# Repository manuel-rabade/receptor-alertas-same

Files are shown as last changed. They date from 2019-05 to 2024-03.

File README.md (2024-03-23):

# Receptor alertas SAME

Este deposito contiene el diseño de hardware y código fuente de mi trabajo de tesis, titulado [Sistema embebido para recibir alertas de riesgo codificadas con el protocolo SAME](http://www.ptolomeo.unam.mx:8080/xmlui/handle/RepoFi/18971), el cual realice para obtener el título de Ingeniero en Computación en la Facultad de Ingeniería de la Universidad Nacional Autónoma de México.

Como resultado de mi proyecto de titulación, se desarrolló un sistema embebido capaz de recibir alertas de riesgo transmitidas mediante el protocolo SAME y difundirlas a través de medios visuales, auditivos o electrónicos. Además, se documentan las bases técnicas para el desarrollo de productos o servicios que amplíen el aprovechamiento y la cobertura de los sistemas de alerta de riesgos.

## Organización

- [hardware](hardware): Diagrama esquemático, diseño de la placa electrónica y lista de componentes electrónicos del receptor.
- [software](software): Implementación del software del receptor. Código fuente de las pruebas unitarias y de integración.
- [logger](logger): Scripts y configuración para recolectar registros de operación.
- [prototipo](prototipo): Diagrama esquemático y software del prototipo del receptor.

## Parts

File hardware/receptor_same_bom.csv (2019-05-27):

Qty | Value | Device | Package | Parts | Description | HOUSEPART | MF | MPN | OC_FARNELL | OC_NEWARK | POPULATE | PROD_ID | SPICEPREFIX | URL | VALUE
7 | 0.1UF | CERAMIC-100NF-50V-10%-X7R(0603) | C0603 | C1, C2, C3, C11, C12, C15, C18 | 302010138 |  |  | CC0603KRX7R9BB104 |  |  |  |  |  |  | 100nf
1 | 1.5K | SMD-RES-1.5K-5%-1/10W(0603) | R0603 | R16 | 301010114 |  |  | RC0603JR-071K5L |  |  |  |  |  |  | 1.5K 1/10W
4 | 10K | SMD-RES-10K-5%-1/10W(0603) | R0603 | R1, R4, R11, R15 | 301010293 |  |  | RC0603JR-0710KL |  |  |  |  |  |  | 10K 1/10W
2 | 10UF | CERAMIC-10UF-6.3V-20%-X5R(0603) | C0603 | C16, C17 | 302010286 |  |  | CC0603MRX5R5BB106 |  |  |  |  |  |  | 10UF 6.3V
1 | 10UF-50V | CERAMIC-10UF-25V-10%-X5R(1206) | C1206 | C14 | 302010181 |  |  | CL31A106KBHNNNE |  |  |  |  |  |  | 10uf
4 | 120 | SMD-RES-120R-5%-1/8W(0805) | R0805 | R9, R10, R12, R13 | 301012183 |  |  | RC0805JR-07120RL |  |  |  |  |  |  | 1K
1 | 1NF | CERAMIC-1NF-50V-5%-C0G(0603) | C0603 | C13 | 302010341 |  |  | GRM1885C1H102JA01D |  |  |  |  |  |  | 1nf
2 | 2.5KNH-50MA | SMD-INDUCTOR-4.7NH-0.3NH-300MA(0402) | L0402 | L2, L3 | 303010037 |  |  | BLM18BD252SN1D |  |  |  |  | L |  | 4.7NH-300MA
2 | 20K | SMD-RES-20K-1%-1/10W(0603) | R0603 | R5, R6 | 301011971 |  |  | RC0603FR-0720KL |  |  |  |  | R |  | 20K
1 | 22NF | CERAMIC-22NF-50V-10%-X7R(0603) | C0603 | C4 | 302010095 |  |  | CC0603KRX7R9BB223 |  |  |  |  |  |  | 22nf
2 | 22PF | CERAMIC-22PF-50V-5%-NPO(0603) | C0603 | C5, C6 | 302010143 |  |  | CC0603JRNPO9BN220 |  |  |  |  | C |  | 22pf
1 | 22UH-2.2A | 303010525_22UH_7.1X6.6MM | L2826 | L4 | SHC0603-220M, SMD Inductor 22uH-20%-0.139R-2.2A;2P-L7.1*W6.6*H3.0mm, SKU: 303010525 |  |  | SHC0603-220M
1 | 3.2768KHZ | SMD-CRYSTAL-32.768KHZ-12.5PF-20PPM-90K(2P-L2.0X1.2MM) | X2-SMD-L2.0X1.2X0.55MM | Y2 | 306010020 |  |  | FC-12M |  |  |  |  | B |  | 3.2768KHZ
2 | 390NF | 390NF-0603-10V-10% | 0603 | C7, C8 | 0.39uF/390nF ceramic capacitors |  |  | CC0603KRX7R6BB394 |  |  |  | CAP-10986 | C |  | 390nF
2 | 4.7K | SMD-RES-4.7K-5%-1/10W(0603) | R0603 | R2, R3 | 301010290 |  |  | RC0603JR-074K7L |  |  |  |  |  |  | 4.7K
1 | 40V-1A | SMD-DIODE-SCHOTTKY-40V-1A(DO-214AC) | DO-214AC | D5 | 304020027 |  |  | 1N5819 |  |  |  |  |  |  | 40V-1A
2 | 47K | SMD-RES-47K-5%-1/10W(0603) | R0603 | R7, R8 | 301010084 |  |  | RC0603JR-0747KL |  |  |  |  | R |  | 47K
2 | 47UF | 47UF-POLAR-EIA3528-10V-10% | EIA3528 | C9, C10 | 47µF polarized capacitors |  |  | TAJB476K010RNJ |  |  |  | CAP-08310 | C |  | 47uF
1 | 52.3K | SMD-RES-51K-5%-1/10W(0603) | R0603 | R14 | 301012135 |  |  | WR06X5232FTL |  |  |  |  |  |  | 51K
1 | 56NH | SPARKFUN-PASSIVES_INDUCTOR0603 | SPARKFUN-PASSIVES_0603 | L1 | Inductors |  |  | SDCL1608C56NJTDF
1 | 8MHZ | RESONATOR-8MHZSMD_3.2X1.3 | RESONATOR-SMD-3.2X1.3 | Y1 | 8MHz Resonator |  |  | CSTCE8M00G55-R0 |  |  |  | XTAL-08895 |  |  | 8MHz
1 | ANTENNA | MPT2 | 2POL254 | X1 | PHOENIX CONNECTOR |  |  | 1725656 | unknown | unknown
1 | ATMEGA328P_TQFP | ATMEGA328P_TQFP | TQFP32-08 | U1 | Popular 328P in QFP |  |  | ATMEGA328P-AU |  |  |  | IC-09069 |  |  | ATMEGA328P_TQFP
1 | AUDIO | MPT3 | 3POL254 | X2 | PHOENIX CONNECTOR |  |  | 1725669 | unknown | unknown |  |  | X
1 | AUX-POWER | DIP-BLACK-MALE-HEADER-VERT(3P-2.54) | H3-2.54 | J4 | 320020079 |  |  | P125-1103A1BS116A1 |  |  |  |  |  |  | 3p-2.54
1 | CM1213 | SPARKFUN-DISCRETESEMI_CM1213 | SPARKFUN-DISCRETESEMI_SOT23-3 | D1 |  |  |  | CM1213A-01SO |  |  |  |  |  | https://www.digikey.com.mx/product-detail/en/on-semiconductor/CM1213A-01SO/CM1213A-01SOOSCT-ND/3462265
1 | GPIO | DIP-BLACK-MALE-HEADER-VERT(8P-2.54) | H8-2.54 | J3 | 320020080 |  |  | P125-1108A1BS116A1 |  |  |  |  |  |  | 8p-2.54
2 | GREEN | SMD-LED-CLEAR-GREEN(0805) | LED-0805 | D2, D3 | 304090057 |  |  | 17-215SYGC/S530-E2/TR8 |  |  |  |  |  |  | GREEN-0805
1 | HLS8L-DC5V | RELAY-HLS8L-DC5V-S-CHLS8L-DC5V-S-C | REY5-19.0X15.0X15.0MM | K1 | 315030000 |  |  | HLS8L-DC5V-S-C
1 | ICSP | DIP-BLACK-MALE-HEADER(2X3P-2.54）-2.54 | H2X3-2.54 | J1 | 320020077 |  |  | P125-12A1BS116A1 |  |  |  |  |  |  | 2x3p-2.54
1 | IO | MPT6 | 6POL254 | X4 | PHOENIX CONNECTOR |  |  | 1725698 | unknown | unknown
1 | MCP16301/H | MCP16301/H | SOT23-6 | U4 | High-Voltage Input Integrated Switch Step-Down Regulator |  |  | MCP16301T-I/CHY
1 | MMBT3904LT1G | SMD-TRANSISTORS-NPN-40V-200MA-MMBT3904LT1G(SOT-23) | SOT-23 | Q1 | 305010013 |  |  | MMBT3904LT1G |  |  |  |  |  |  | MMBT3904LT1G
2 | MMSD4148 | SMD-DIODE-100V-200MA(SOD-123) | SOD-123 | D4, D6 | 304010007 |  |  | MMSD4148 |  |  |  |  |  |  | MMSD4148-sod123
4 | MOUNT-HOLE4.1 | MOUNT-HOLE4.1 | 4,1 | H1, H2, H3, H4 | MOUNTING HOLE with drill center marker
1 | POWER | MPT2 | 2POL254 | X5 | PHOENIX CONNECTOR |  |  | 1725656 | unknown | unknown
1 | RELAY | MKDSN1,5/3-5,08 | MKDSN1,5/3-5,08 | X3 | MKDSN 1,5/ 3-5,08 Printklemme |  |  | 1715734
1 | SERIAL | DIP-BLACK-MALE-HEADER(6P-2.54) | H6-2.54 | J2 | 320020078 |  |  | P125-1106A1BS116A1 |  |  |  |  | X |  | 6p-2.54
1 | SI4707 | SPARKFUN-RF_SI4707 | SPARKFUN-RF_SI470X | U2 | Silicon Labs Si4707 Weather Band and SAME Data Receiver |  |  | SI4707-B20-GM |  |  |  |  | X | https://www.digikey.com/product-detail/en/silicon-labs/SI4707-B20-GM/336-2147-ND/2686997
1 | TLV70233DBVR | TLV70233PDBVR | SOT-23-5 | U5 | Manufacturer Part #: TLV702 | YES |  | TLV70233DBVR |  |  | 1 |  |  |  | MF-REG-SOT235-3.3V-300mA
1 | TPA6111A2DR | TPA6111SMD-T | SO08 | U3 | TPA6111A2 |  |  | TPA6111A2DR |  |  |  | IC-10149 | X | https://www.digikey.com/product-detail/en/texas-instruments/TPA6111A2DR/296-10846-1-ND/381452 | TPA6111A2DR

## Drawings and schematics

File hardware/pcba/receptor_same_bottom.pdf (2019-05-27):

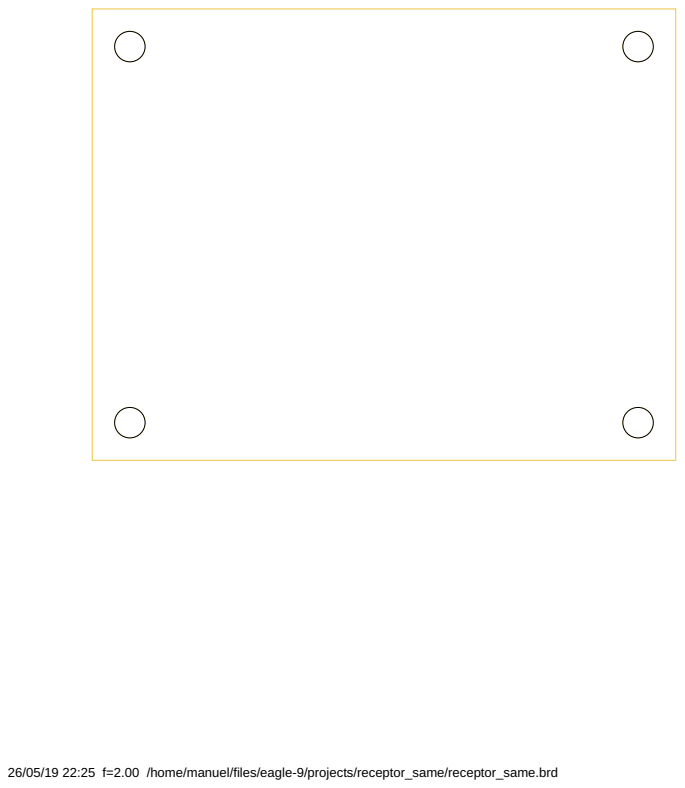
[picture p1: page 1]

26/05/19 22:25 f=2.00 /home/manuel/files/eagle-9/projects/receptor_same/receptor_same.brd

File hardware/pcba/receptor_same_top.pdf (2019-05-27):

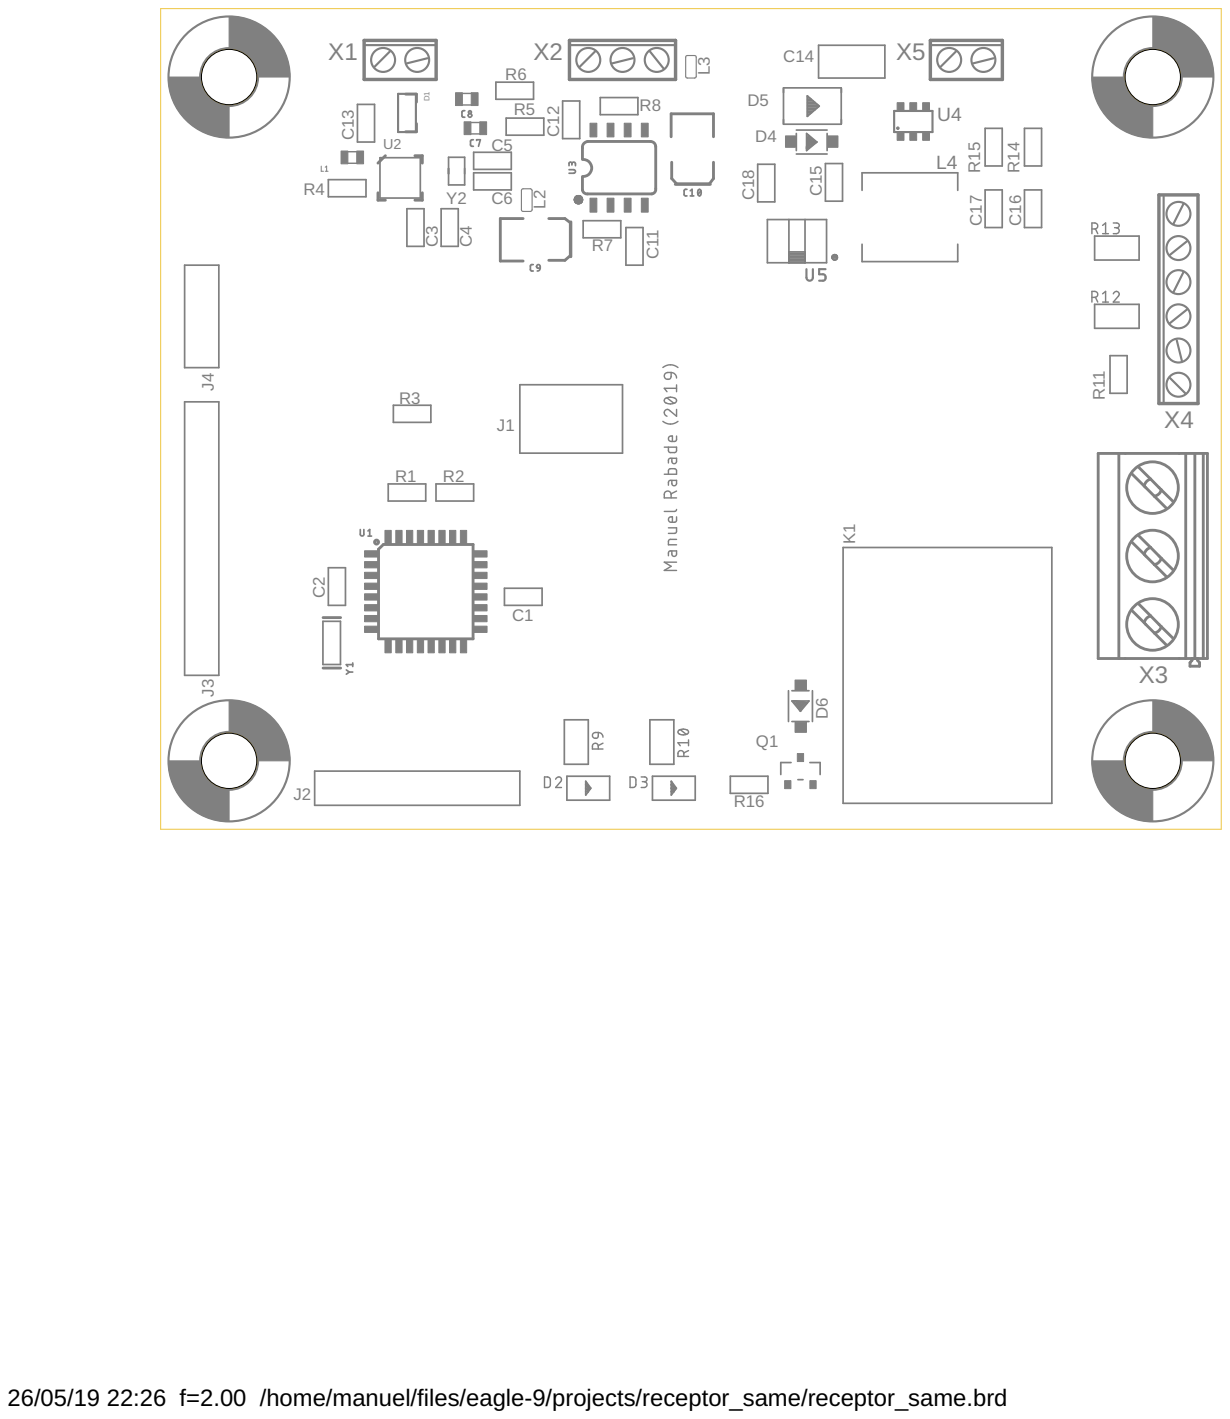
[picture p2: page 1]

26/05/19 22:26 f=2.00 /home/manuel/files/eagle-9/projects/receptor_same/receptor_same.brd

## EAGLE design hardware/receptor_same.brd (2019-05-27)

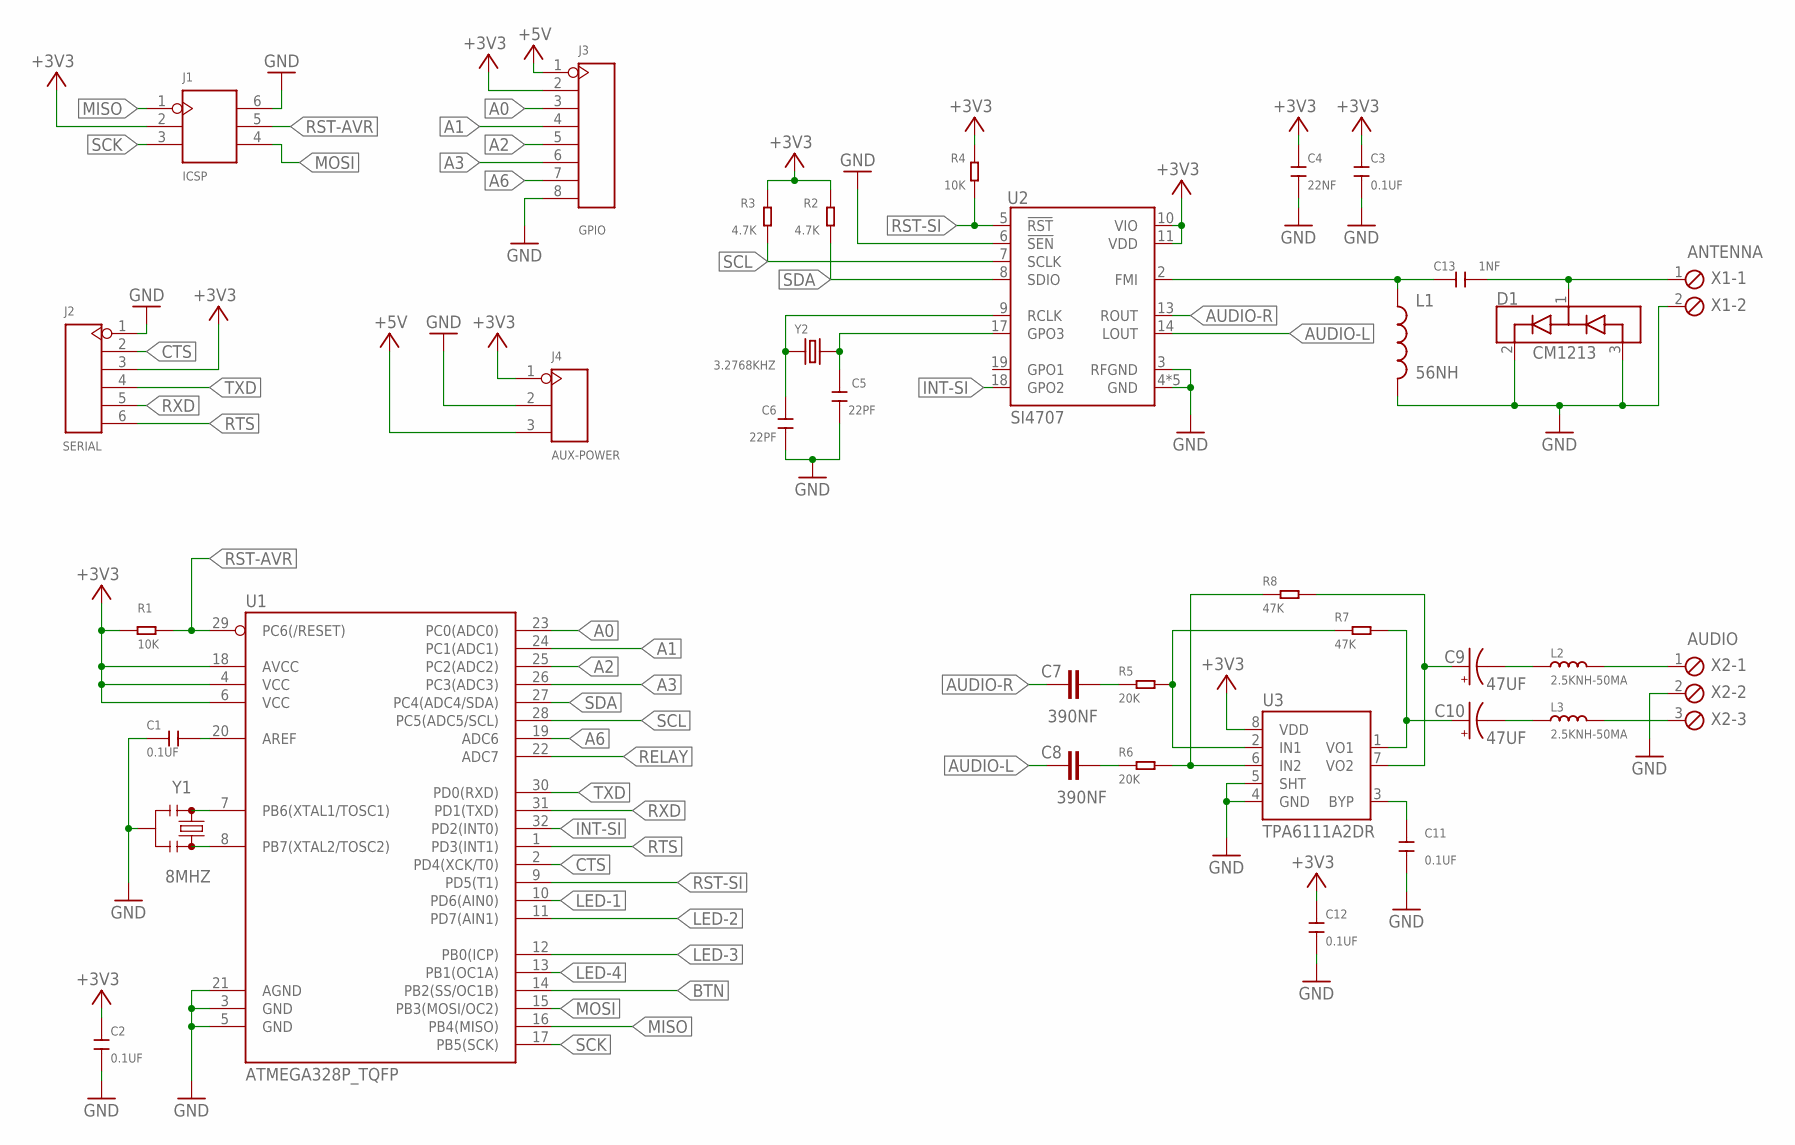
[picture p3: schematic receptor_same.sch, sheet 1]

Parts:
C1, C2, C3, C11, C12: 0.1UF; C0603
C4: 22NF; C0603
C5, C6: 22PF; C0603
C7, C8: 390NF; 0603; MPN CC0603KRX7R6BB394
C9, C10: 47UF; EIA3528; MPN TAJB476K010RNJ
C13: 1NF; C0603
D1: CM1213; SPARKFUN-DISCRETESEMI_SOT23-3; MPN CM1213A-01SO
J1: ICSP; H2X3-2.54
J2: SERIAL; H6-2.54
J3: GPIO; H8-2.54
J4: AUX-POWER; H3-2.54; MPN P125-1103A1BS116A1
L1: 56NH; SPARKFUN-PASSIVES_0603; MPN SDCL1608C56NJTDF
L2, L3: 2.5KNH-50MA; L0402; MPN BLM18BD252SN1D
R1, R4: 10K; R0603
R2, R3: 4.7K; R0603
R5, R6: 20K; R0603
R7, R8: 47K; R0603
U1: ATMEGA328P_TQFP; TQFP32-08; MPN ATMEGA328P-AU
U2: SI4707; SPARKFUN-RF_SI470X; MPN SI4707-B20-GM
U3: TPA6111A2DR; SO08; MPN TPA6111A2DR
X1: ANTENNA; 2POL254; MPN 1725656
X2: AUDIO; 3POL254; MPN 1725669
Y1: 8MHZ; RESONATOR-SMD-3.2X1.3; MPN CSTCE8M00G55-R0
Y2: 3.2768KHZ; X2-SMD-L2.0X1.2X0.55MM

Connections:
+3V3: C2.1, C3.1, C4.1, C12.1, J1.2, J2.3, J3.2, J4.1, R1.2, R2.1, R3.1, R4.1, U1.4 (VCC), U1.6 (VCC), U1.18 (AVCC), U2.10 (VIO), U2.11 (VDD), U3.8 (VDD); also elsewhere on the board
+5V: J3.1, J4.3; also elsewhere on the board
A0: J3.3, U1.23 (PC0(ADC0))
A1: J3.4, U1.24 (PC1(ADC1))
A2: J3.5, U1.25 (PC2(ADC2))
A3: J3.6, U1.26 (PC3(ADC3))
A6: J3.7, U1.19 (ADC6)
AUDIO-L: C8.1, U2.14 (LOUT)
AUDIO-R: C7.1, U2.13 (ROUT)
BTN: U1.14 (PB2(SS/OC1B)); also elsewhere on the board
CTS: J2.2, U1.2 (PD4(XCK/T0))
GND: C1.1, C2.2, C3.2, C4.2, C5.1, C6.1, C11.2, C12.2, D1.2 (VP), D1.3 (VN), J1.6, J2.1, J3.8, J4.2, L1.2, U1.3 (GND), U1.5 (GND), U1.21 (AGND), U2.3 (RFGND), U2.4 (GND), U2.6 (!SEN), U2.12 (GND), U2.15 (GND), U2.16 (GND), U2.21 (GND), U3.4 (GND), U3.5 (SHT), X1.2, X2.2, Y1.2; also elsewhere on the board
INT-SI: U1.32 (PD2(INT0)), U2.18 (GPO2)
L: L2.2, X2.1
LED-1: U1.10 (PD6(AIN0)); also elsewhere on the board
LED-2: U1.11 (PD7(AIN1)); also elsewhere on the board
LED-3: U1.12 (PB0(ICP)); also elsewhere on the board
LED-4: U1.13 (PB1(OC1A)); also elsewhere on the board
MISO: J1.1, U1.16 (PB4(MISO))
MOSI: J1.4, U1.15 (PB3(MOSI/OC2))
unnamed: U1.7 (PB6(XTAL1/TOSC1)), Y1.1
unnamed: U1.8 (PB7(XTAL2/TOSC2)), Y1.3
unnamed: C1.2, U1.20 (AREF)
unnamed: C5.2, U2.17 (GPO3), Y2.2
unnamed: C6.2, U2.9 (RCLK), Y2.1
unnamed: C13.1, L1.1, U2.2 (FMI)
unnamed: C7.2, R5.1
unnamed: C8.2, R6.1
unnamed: C11.1, U3.3 (BYP)
unnamed: R5.2, R7.1, U3.2 (IN1)
unnamed: C10.A (+), R7.2, U3.1 (VO1)
unnamed: R6.2, R8.1, U3.6 (IN2)
unnamed: C9.A (+), R8.2, U3.7 (VO2)
unnamed: C9.C (-), L2.1
unnamed: C10.C (-), L3.1
unnamed: C13.2, D1.1 (CH1), X1.1
R: L3.2, X2.3
RELAY: U1.22 (ADC7); also elsewhere on the board
RST-AVR: J1.5, R1.1, U1.29 (PC6(/RESET))
RST-SI: R4.2, U1.9 (PD5(T1)), U2.5 (!RST)
RTS: J2.6, U1.1 (PD3(INT1))
RXD: J2.5, U1.31 (PD1(TXD))
SCK: J1.3, U1.17 (PB5(SCK))
SCL: R3.2, U1.28 (PC5(ADC5/SCL)), U2.7 (SCLK)
SDA: R2.2, U1.27 (PC4(ADC4/SDA)), U2.8 (SDIO)
TXD: J2.4, U1.30 (PD0(RXD))

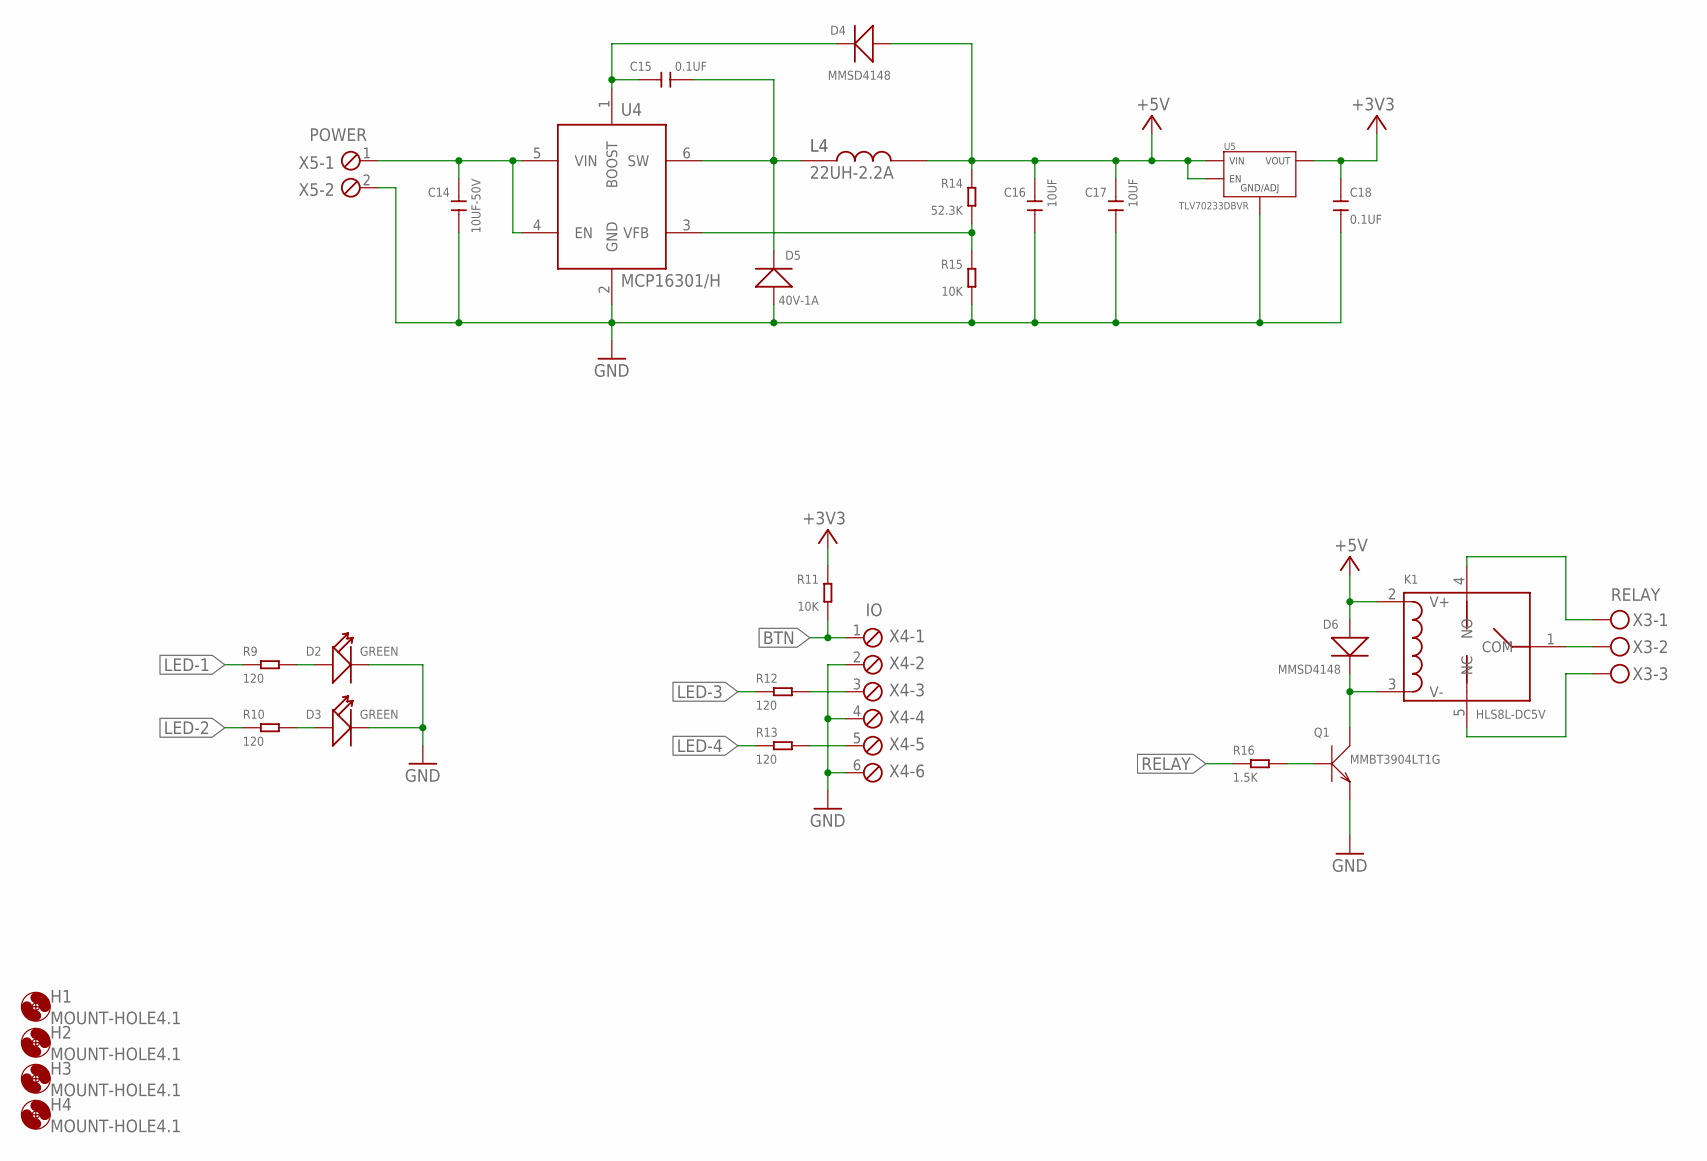
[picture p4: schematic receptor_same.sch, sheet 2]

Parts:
C14: 10UF-50V; C1206; MPN CL31A106KBHNNNE
C15, C18: 0.1UF; C0603
C16, C17: 10UF; C0603
D2, D3: GREEN; LED-0805
D4, D6: MMSD4148; SOD-123
D5: 40V-1A; DO-214AC
H1, H2, H3, H4: MOUNT-HOLE4.1; 4,1
K1: HLS8L-DC5V; REY5-19.0X15.0X15.0MM; MPN HLS8L-DC5V-S-C
L4: 22UH-2.2A; L2826; MPN SHC0603-220M
Q1: MMBT3904LT1G; SOT-23
R9, R10, R12, R13: 120; R0805; MPN RC0805JR-07120RL
R11, R15: 10K; R0603
R14: 52.3K; R0603; MPN WR06X5232FTL
R16: 1.5K; R0603
U4: MCP16301/H; SOT23-6; MPN MCP16301T-I/CHY
U5: TLV70233DBVR; SOT-23-5; MPN TLV70233DBVR
X3: RELAY; MKDSN1,5/3-5,08; MPN 1715734
X4: IO; 6POL254; MPN 1725698
X5: POWER; 2POL254; MPN 1725656

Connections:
+3V3: C18.1, R11.1, U5.P$5 (VOUT); also elsewhere on the board
+5V: C16.2, C17.2, D4.+, D6.+, K1.2 (V+), L4.P$2, R14.2, U5.P$1 (VIN), U5.P$3 (EN); also elsewhere on the board
BTN: R11.2, X4.1; also elsewhere on the board
GND: C14.1, C16.1, C17.1, C18.2, D2.-, D3.-, D5.1 (+), Q1.2 (E), R15.2, U4.2 (GND), U5.P$2 (GND/ADJ), X4.2, X4.4, X4.6, X5.2; also elsewhere on the board
LED-1: R9.1; also elsewhere on the board
LED-2: R10.1; also elsewhere on the board
LED-3: R12.1; also elsewhere on the board
LED-4: R13.1; also elsewhere on the board
unnamed: R12.2, X4.3
unnamed: D3.+, R10.2
unnamed: D2.+, R9.2
unnamed: R13.2, X4.5
unnamed: C15.2, D4.-, U4.1 (BOOST)
unnamed: K1.1 (COM), X3.2
unnamed: R14.1, R15.1, U4.3 (VFB)
unnamed: K1.4 (NO), X3.1
unnamed: K1.5 (NC), X3.3
unnamed: D6.-, K1.3 (V-), Q1.3 (C)
unnamed: Q1.1 (B), R16.2
RELAY: R16.1; also elsewhere on the board
SW: C15.1, D5.2 (-), L4.P$1, U4.6 (SW)
VIN: C14.2, U4.4 (EN), U4.5 (VIN), X5.1

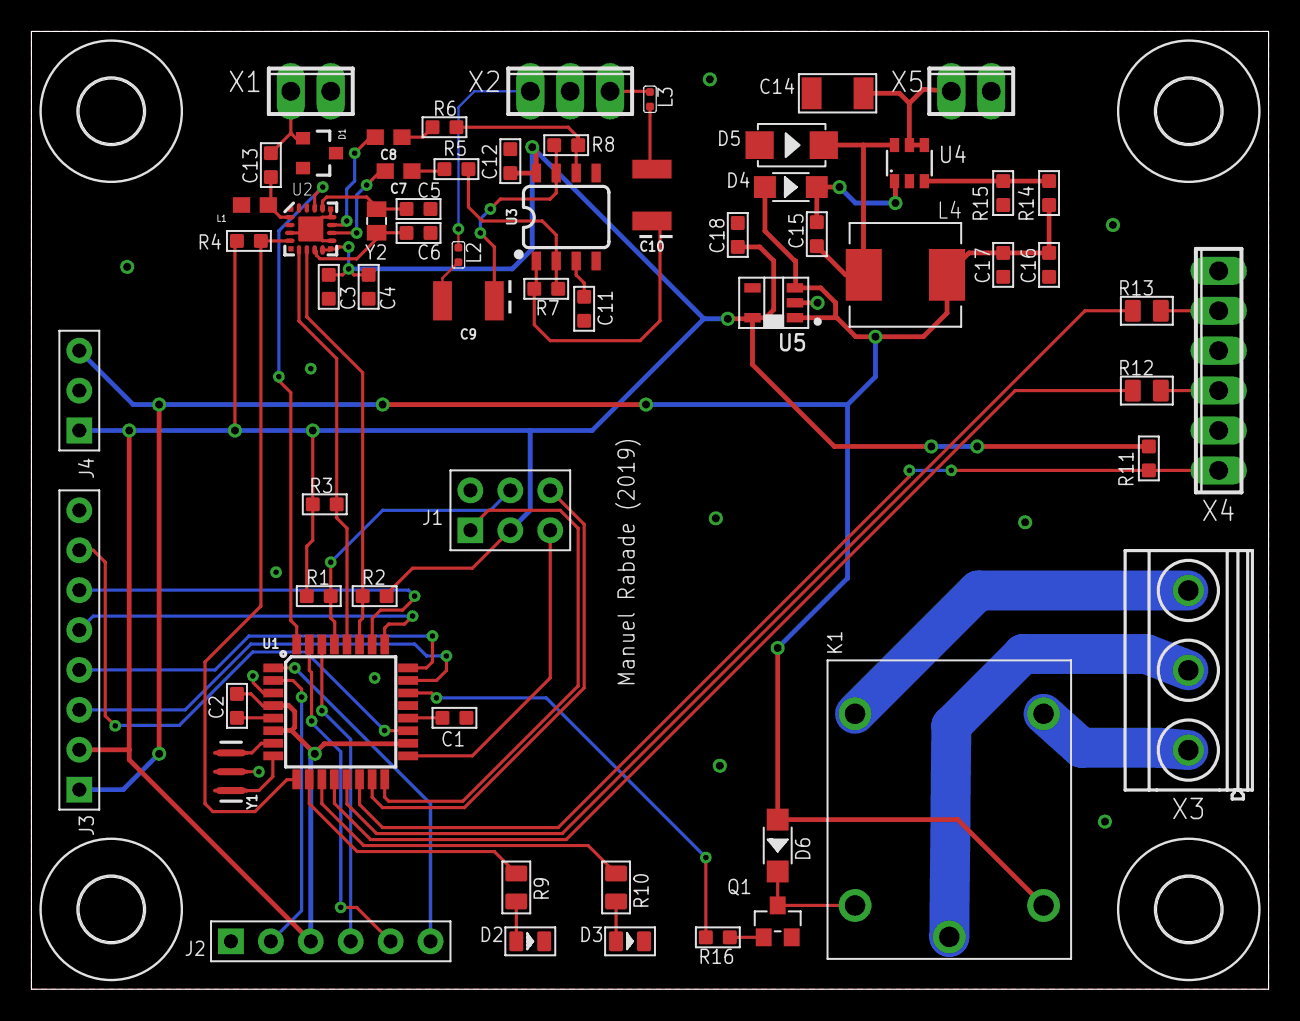
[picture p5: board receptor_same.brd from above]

Board: 2 copper layers, 78.7 x 61.0 mm, 66 parts (0 on the bottom side), 59 nets.

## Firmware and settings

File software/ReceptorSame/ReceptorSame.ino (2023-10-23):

#include "Si4707.h"
#include "MockRadio.h"
#include "IO.h"
#include "Command.h"
#include "Config.h"

// configuración
#define CONFIG_VERSION 0x12 // versión memoria
#define SAME_TIMEOUT 6000 // tiempo de espera maximo para recibir un mensaje same completo (segundos)
#define ALERT_CDMX_MILLIS 60000 // tiempo de duracion alerta para cdmx

// maquina de estados same
#define SAME_EOM_DET 0
#define SAME_PRE_DET 1
#define SAME_HDR_DET 2
#define SAME_HDR_RDY 3

// constantes globales
const unsigned long sameChannels[] = { // canales same (1 a 7) -> frecuencias radio (hertz)
  162400, 162425, 162450, 162475, 162500, 162525, 162550 };
const byte radioVolumes[] = { // volumen configuración (0 a 10) -> volumen radio (0 a 63)
  0, 6, 13, 19, 25, 32, 38, 44, 50, 57, 63 };

// radio
#if MOCKRADIO == 0 // 0 = si4707, > 0 caso de prueba con radio simulado
Si4707 radio;
#else
MockRadio radio; // radio simulado
#endif

// objetos globales
IO io;
Command cmd;
Config config;

// variables globales
boolean asqPrevStatus = 0; // estado asq
byte samePrevState = 0; // estado same
byte sameHeadersCount = 0; // conteo de cabeceras
boolean sameTimerEnabled = false;  // timer mensaje same
unsigned long sameTimer = 0;
boolean sameAlert = false; // estado alerta
boolean testAlert = false; // estado prueba de alerta
boolean relayState = false; // status relay
boolean audioState = false; // status audio

// pruebas same
boolean sameRwtEnabled = false;  // timer prueba semanal
unsigned long sameRwtTimer = 0;
boolean sameRmtEnabled = false;  // timer prueba mensual
unsigned long sameRmtTimer = 0;

void setup() {
  // inicio leds
  io.ledsBegin();

  // inicia puerto serial
  Serial.begin(9600);
  Serial.println(F("STARTUP"));

  // verificacion de memoria
  Serial.print(F("CONFIG_VERSION,"));
  Serial.println(config.getVersion());
  if (config.getVersion() != CONFIG_VERSION) {
    configDefaults();
    configSave();
  }

  // inicio si4707
  if (radio.begin()) {
    Serial.println(F("SI4707_OK"));
  } else {
    Serial.print(F("SI4707_ERROR"));
    io.ledsError();
    while (1) {
      io.refresh();
      delay(10);
    }
  }

  // aplicar configuacion
  updateSettings();
  io.ledsWait();
  Serial.println(F("RUN"));
}

void loop() {
  // monitor tono 1050 khz
  boolean asqStatus = radio.getASQ();
  if (asqPrevStatus != asqStatus) {
    if (asqStatus) {
      Serial.println("ASQ_ON");
      audioOn();
      sameReset();
    } else {
      Serial.println("ASQ_OFF");
    }
    asqPrevStatus = asqStatus;
  }

  // recepción mensajes same
  byte sameState = radio.getSAMEState();
  if (samePrevState != sameState) {
    samePrevState = sameState;
    switch (sameState) {
    case SAME_EOM_DET:
      // fin del mensaje
      Serial.println("SAME_EOM_DET");
      sameEnd();
      break;
    case SAME_PRE_DET:
      // preámbulo detectado
      sameRefreshTimer();
      Serial.println("SAME_PRE_DET");
      break;
    case SAME_HDR_DET:
      // cabecera detectada
      sameRefreshTimer();
      Serial.println("SAME_HDR_DET");
      break;
    case SAME_HDR_RDY:
      // cabecera lista
      sameRefreshTimer();
      sameHeadersCount++;
      Serial.print("SAME_HDR_RDY,");
      Serial.println(sameHeadersCount);
      // ¿se recibieron 3 cabeceras?
      if (sameHeadersCount == 3) {
        sameMessage();
      }
      break;
    }
  }

  // timeout mensaje same
  if (sameTimerEnabled && millis() - sameTimer > SAME_TIMEOUT) {
    Serial.println("SAME_TIMEOUT");
    // ¿se recibieron al menos 2 cabeceras?
    if (sameHeadersCount > 1) {
      sameMessage();
    } else {
      sameReset();
    }
  }

  // timeout prueba semanal
  if (sameRwtEnabled && millis() - sameRwtTimer > config.getRwtPeriodMillis()) {
    sameRwtEnabled = false;
    sameRwtTimer = 0;
    Serial.println("SAME_RWT_TIMEOUT");
    io.ledsWait();
  }

  // timeout prueba mensual
  if (sameRmtEnabled && millis() - sameRmtTimer > config.getRmtPeriodMillis()) {
    sameRmtEnabled = false;
    sameRmtTimer = 0;
    Serial.println("SAME_RMT_TIMEOUT");
    io.ledsWait();
  }

  // procesar comandos seriales
  if (cmd.isReady()) {
    commands();
    cmd.clearBuffer();
  }

  // boton de usuario
  if (io.isButtonTriggered()) {
    Serial.println("BUTTON_TRIGGERED");
    if (sameAlert) {
      audioOff();
      relayOff();
      Serial.println("SAME_ALERT_OFF");
      sameAlert = false;
      if (sameRwtEnabled || sameRmtEnabled) {
        io.ledsWaitRT();
      } else {
        io.ledsWait();
      }
    } else if (relayState && !testAlert) {
      relayOff();
    } else if (testAlert) {
      Serial.println("TEST_ALERT_OFF");
      testAlert = false;
      audioOff();
      relayOff();
      if (sameRwtEnabled || sameRmtEnabled) {
        io.ledsWaitRT();
      } else {
        io.ledsWait();
      }
    } else {
      Serial.println("TEST_ALERT_ON");
      testAlert = true;
      io.ledsAlert();
      audioOn();
      relayOn();
    }
  }

  // refrescar io
  io.refresh();
  delay(10);
}

// ---------------------------------------------------------------------------
// same

// procesar mensaje same
void sameMessage() {
  byte size = radio.getSAMESize();
  // ¿mensaje vacío?
  if (size < 1) {
    Serial.println("SAME_EMPTY");
    return;
  }

  // adquisición mensaje
  byte msg[size];
  radio.getSAMEMessage(size, msg);
  sameReset();

  // reportamos mensaje
  Serial.print("SAME_MESSAGE,");
  for (byte i = 0; i < size; i++) {
    if (msg[i] > 31 && msg[i] < 127) {
      Serial.write(msg[i]);
    } else {
      Serial.print(".");
    }
  }
  Serial.println();

  // evento del mensaje
  char event[3] = { msg[5], msg[6], msg[7] };

  // areas del mensaje
  char areas[31][6];
  byte areasCount = 0;
  while (areasCount < 31) {
    byte offset = 8 + areasCount * 7;
    if (strncmp(msg + offset, "-", 1) == 0) {
      strncpy(areas[areasCount], msg + offset + 1, 6);
      areasCount++;
    } else {
      break;
    }
  }

  // filtramos codigo de area
  if (config.countAreaCodes() > 0){
    boolean areaFlag = false;
    for (byte i; i < areasCount; i++) {
      if (config.findAreaCodeWildcard(areas[i])) {
        areaFlag = true;
        break;
      }
    }
    if (!areaFlag) {
      Serial.println("SAME_IGNORE_AREA");
      return;
    }
  }

  // mensaje de prueba
  if (strncmp(event, "RWT", 3) == 0) {
    Serial.println("SAME_RWT");
    if (config.getRwtPeriod() > 0) {
      sameRwtEnabled = true;
      sameRwtTimer = millis();
      io.ledsWaitRT();
    }
    return;
  } else if (strncmp(event, "RMT", 3) == 0) {
    Serial.println("SAME_RMT");
    if (config.getRmtPeriod() > 0) {
      sameRmtEnabled = true;
      sameRmtTimer = millis();
      io.ledsWaitRT();
    }
    return;
  }

  // filtramos codigo de evento
  if (config.countEventCodes() > 0 && !config.findEventCode(event)) {
    Serial.println("SAME_IGNORE_EVENT");
    return;
  }

  // alerta cdmx
  if (strncmp(event, "EQW", 3) == 0 && config.getCDMX()) {
    Serial.println("CDMX_ALERT_ON");
    alertCDMX();
    Serial.println("CDMX_ALERT_OFF");
    return;
  }

  // disparamos alerta
  Serial.println("SAME_ALERT_ON");
  sameAlert = true;
  io.ledsAlert();
  if (config.getRelay() > 1) {
    relayOn();
  }
  audioOn();
}

// fin mensaje same
void sameEnd() {
  if (sameAlert) {
    audioOff();
    if (config.getRelay() == 2) {
      relayOff();
    }
    if (config.getRelay() < 3) {
      Serial.println("SAME_ALERT_OFF");
      sameAlert = false;
      if (sameRwtEnabled || sameRmtEnabled) {
        io.ledsWaitRT();
      } else {
        io.ledsWait();
      }
    }
  }
  // ¿se recibieron 2 cabeceras?
  if (sameHeadersCount == 2) {
    sameMessage();
  }
  sameReset();
}

// actualizar timer same
void sameRefreshTimer() {
  sameTimerEnabled = true;
  sameTimer = millis();
}

// reiniciar buffer, timer y contador same
void sameReset() {
  radio.clearSAMEBuffer();
  sameTimerEnabled = false;
  sameTimer = 0;
  sameHeadersCount = 0;
}

// ---------------------------------------------------------------------------
// disparo audio y relay

void audioOn() {
  if (!audioState) {
    Serial.println("AUDIO_ON");
    radio.setMuteVolume(false);
    audioState = true;
    if (config.getRelay() == 1) {
      relayOn();
    }
  }
}

void audioOff() {
  if (audioState) {
    Serial.println("AUDIO_OFF");
    radio.setMuteVolume(true);
    audioState = false;
    if (config.getRelay() == 1) {
      relayOff();
    }
  }
}

void relayOn() {
  if (!relayState) {
    Serial.println("RELAY_ON");
    io.relayOn();
    relayState = true;
  }
}

void relayOff() {
  if (relayState) {
    Serial.println("RELAY_OFF");
    io.relayOff();
    relayState = false;
  }
}

// ---------------------------------------------------------------------------
// alerta cdmx

void alertCDMX () {
  io.audioPlayOn();
  io.ledsAlert();
  if (config.getRelay() > 0) {
    relayOn();
  }
  unsigned long alertTimer = millis();
  while (millis() - alertTimer < ALERT_CDMX_MILLIS) {
    // descartamos mensajes same
    byte sameState = radio.getSAMEState();
    if (samePrevState != sameState) {
      samePrevState = sameState;
      switch (sameState) {
      case SAME_EOM_DET:
        Serial.println("SAME_EOM_DET");
        break;
      case SAME_PRE_DET:
        Serial.println("SAME_PRE_DET");
        break;
      case SAME_HDR_DET:
        Serial.println("SAME_HDR_DET");
        break;
      case SAME_HDR_RDY:
        Serial.println("SAME_HDR_RDY");
        break;
      }
    }
    // refrescar io
    io.refresh();
    delay(10);
  }
  io.audioPlayOff();
  if (sameRwtEnabled || sameRmtEnabled) {
    io.ledsWaitRT();
  } else {
    io.ledsWait();
  }
  relayOff();
}

// ---------------------------------------------------------------------------
// aplicar configuracion

// todas las configuraciones
void updateSettings() {
  updateMute();
  updateVolume();
  updateChannel();
}

// ajuste de mute
void updateMute() {
  radio.setMuteVolume(config.getMute());
  Serial.print(F("MUTE,"));
  Serial.println(config.getMute());
}

// ajuste de volumen
void updateVolume() {
  radio.setVolume(radioVolumes[config.getVolume()]);
  Serial.print(F("VOLUME,"));
  Serial.println(config.getVolume());
}

// sintonizar canal
void updateChannel() {
  if (radio.setWBFrequency(sameChannels[config.getChannel() - 1])) {
    Serial.print(F("TUNE_OK,"));
  } else {
    Serial.print(F("TUNE_ERROR,"));
  }
  Serial.println(config.getChannel());
}

// ---------------------------------------------------------------------------
// configuración y comandos

void commands() {
  switch (cmd.getCmd()) {
  case CMD_FREQUENCY:
    Serial.print(F("FREQUENCY,"));
    Serial.println((float) radio.getWBFrequency() * 0.0025, 4);
    break;
  case CMD_QUALITY:
    Serial.print(F("QUALITY,"));
    Serial.print(radio.getRSSI());
    Serial.print(F(","));
    Serial.println(radio.getSNR());
    break;
  case CMD_CHANNEL:
    if (cmd.isArg()) {
      byte channel = cmd.getArgByte();
      if (config.setChannel(channel)) {
        updateChannel();
        break;
      }
    }
    Serial.println(F("CHANNEL_ERROR"));
    break;
  case CMD_MUTE:
    if (cmd.isArg()) {
      byte mute = cmd.getArgByte();
      if (mute == 1) {
        config.setMute(true);
        updateMute();
        break;
      } else if (mute == 0) {
        config.setMute(false);
        updateMute();
        break;
      }
    }
    Serial.println(F("MUTE_ERROR"));
    break;
  case CMD_VOLUME:
    if (cmd.isArg()) {
      byte volume = cmd.getArgByte();
      if (config.setVolume(volume)) {
        updateVolume();
        break;
      }
    }
    Serial.println(F("VOLUME_ERROR"));
    break;
  case CMD_RELAY:
    if (cmd.isArg()) {
      byte relay = cmd.getArgByte();
      if (config.setRelay(relay)) {
        Serial.print(F("RELAY,"));
        Serial.println(config.getRelay());
        break;
      }
    }
    Serial.println(F("RELAY_ERROR"));
    break;
  case CMD_CDMX:
    if (cmd.isArg()) {
      byte cdmx = cmd.getArgByte();
      if (cdmx == 1) {
        config.setCDMX(true);
      } else if (cdmx == 0) {
        config.setCDMX(false);
      }
      Serial.print(F("CDMX,"));
      Serial.println(config.getCDMX());
      break;
    }
    Serial.println(F("CDMX_ERROR"));
    break;
  case CMD_RWT_PERIOD:
    if (cmd.isArg()) {
      unsigned int period = cmd.getArgUInt();
      config.setRwtPeriod(period);
      Serial.print(F("RWT_PERIOD,"));
      Serial.println(period);
    } else {
      Serial.println(F("RWT_PERIOD_ERROR"));
    }
    break;
  case CMD_RMT_PERIOD:
    if (cmd.isArg()) {
      unsigned int period = cmd.getArgUInt();
      config.setRmtPeriod(period);
      Serial.print(F("RMT_PERIOD,"));
      Serial.println(period);
    } else {
      Serial.println(F("RMT_PERIOD_ERROR"));
    }
    break;
  case CMD_DEFAULTS:
    configDefaults();
    updateSettings();
    break;
  case CMD_RELOAD:
    Serial.println(F("MEM_RELOAD"));
    config.reload();
    updateSettings();
    break;
  case CMD_SAVE:
    configSave();
    break;
  case CMD_DUMP:
    configDump();
    break;
  case CMD_AREA_ADD:
    if (!cmd.isArg()) {
      Serial.println(F("AREA_ADD_ERROR"));
    } else {
      char* code = cmd.getArg();
      if (config.setAreaCode(code)) {
        Serial.print(F("AREA_ADD_OK,"));
        Serial.println(code);
      } else {
        Serial.println(F("AREA_ADD_ERROR"));
      }
      free(code);
    }
    break;
  case CMD_AREA_DEL:
    if (!cmd.isArg()) {
      Serial.println(F("AREA_DEL_ERROR"));
    } else {
      char* code = cmd.getArg();
      if (config.clearAreaCode(code)) {
        Serial.print(F("AREA_DEL_OK,"));
        Serial.println(code);
      } else {
        Serial.println(F("AREA_DEL_ERROR"));
      }
      free(code);
    }
    break;
  case CMD_EVENT_ADD:
    if (!cmd.isArg()) {
      Serial.println(F("EVENT_ADD_ERROR"));
    } else {
      char* code = cmd.getArg();
      if (config.setEventCode(code)) {
        Serial.print(F("EVENT_ADD_OK,"));
        Serial.println(code);
      } else {
        Serial.println(F("EVENT_ADD_ERROR"));
      }
      free(code);
    }
    break;
  case CMD_EVENT_DEL:
    if (!cmd.isArg()) {
      Serial.println(F("EVENT_DEL_ERROR"));
    } else {
      char* code = cmd.getArg();
      if (config.clearEventCode(code)) {
        Serial.print(F("EVENT_DEL_OK,"));
        Serial.println(code);
      } else {
        Serial.println(F("EVENT_DEL_ERROR"));
      }
      free(code);
    }
    break;
  default:
    Serial.println(F("UNKNOWN_COMMAND"));
  }
}

void configDefaults() {
  Serial.println(F("CONFIG_DEFAULTS"));
  config.setVersion(CONFIG_VERSION);
  config.setChannel(7);
  config.setMute(true);
  config.setVolume(10);
  config.setRelay(1);
  config.setCDMX(true);
  config.setRwtPeriod(0);
  config.setRmtPeriod(0);
  config.emptyAreaCodes();
  config.emptyEventCodes();
}

void configSave() {
  Serial.println(F("MEM_SAVE"));
  config.save();
}

void configDump() {
  Serial.print(F("CONFIG_VERSION,"));
  Serial.println(config.getVersion());
  Serial.print(F("CONFIG_CHANNEL,"));
  Serial.println(config.getChannel());
  Serial.print(F("CONFIG_MUTE,"));
  Serial.println(config.getMute());
  Serial.print(F("CONFIG_VOLUME,"));
  Serial.println(config.getVolume());
  Serial.print(F("CONFIG_RELAY,"));
  Serial.println(config.getRelay());
  Serial.print(F("CONFIG_CDMX,"));
  Serial.println(config.getCDMX());
  Serial.print(F("CONFIG_RWT_PERIOD,"));
  Serial.println(config.getRwtPeriod());
  Serial.print(F("CONFIG_RMT_PERIOD,"));
  Serial.println(config.getRmtPeriod());
  Serial.print(F("CONFIG_AREA_CODES,"));
  Serial.println(config.countAreaCodes());
  for (byte idx = 0; idx < config.countAreaCodes(); idx++) {
    Serial.print(F("CONFIG_AREA_CODE,"));
    Serial.print(idx);
    Serial.print(F(","));
    char* code = config.strAreaCode(idx);
    Serial.println(code);
    free(code);
  }
  Serial.print(F("CONFIG_EVENT_CODES,"));
  Serial.println(config.countEventCodes());
  for (byte idx = 0; idx < config.countEventCodes(); idx++) {
    Serial.print(F("CONFIG_EVENT_CODE,"));
    Serial.print(idx);
    Serial.print(F(","));
    char* code = config.strEventCode(idx);
    Serial.println(code);
    free(code);
  }
}

// Local Variables:
// mode: c++
// End:

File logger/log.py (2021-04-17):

#!/usr/bin/python

import serial
import time
import csv
import sys
import os

port = serial.Serial(sys.argv[1])
port.flushInput()

while True:
    line = port.readline()
    txt = line.decode('ascii').rstrip()
    timestamp = time.strftime('%Y-%m-%d %H:%M:%S')
    print(timestamp + ' -> ' + txt)
    filename = time.strftime('%Y-%m-%d.log')
    with open(os.path.join(sys.argv[2], filename),"a") as f:
        writer = csv.writer(f,delimiter=",")
        writer.writerow([time.strftime('%Y-%m-%d'), time.strftime('%H:%M:%S'), time.time(), txt])

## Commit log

2019-05-06 mcu y xtal en sch
    [receptor_same.sch]
2019-05-09 avances mcu
    [receptor_same.sch]
2019-05-09 separamos icsp
    [receptor_same.sch]
2019-05-10 biblioteca si4707 de sparkfun
2019-05-10 avances si4707 y conctor puerto serial
    [receptor_same.sch]
2019-05-11 borramos biblioteca si4707 y agregamos la del breakout de sparkfun completo
2019-05-12 terminamos si4707, tda611, io, gpio y leds
    [receptor_same.sch]
2019-05-14 bibliotecas de partes
2019-05-14 fuente de poder
    [receptor_same.sch]
2019-05-14 120 para resistencias de leds (12.5 mA)
    [receptor_same.sch]
2019-05-14 bibliotecas de eagle en hardware
2019-05-14 segunda hoja: relay y aux power
    [receptor_same.sch]
2019-05-14 fix mpn conector 3 pines
    [receptor_same.sch]
2019-05-15 ajustes bom y posicion en hoja
    [receptor_same.sch]
2019-05-15 ajustamos values a mayusculas
    [receptor_same.sch]
2019-05-15 ajutes values caps
    [receptor_same.sch]
2019-05-16 puntos de montaje en esquematico y pasa el erc
    [receptor_same.sch]
2019-05-16 arrancamos el ruteo!
    [receptor_same.brd]
2019-05-16 avances si4707 y audio
    [receptor_same.brd]
2019-05-16 avances ruteo si + amp
    [receptor_same.brd, receptor_same.sch]
2019-05-16 avances pcba
    [receptor_same.brd, receptor_same.sch]
2019-05-26 pcb terminado
    [receptor_same.brd, receptor_same.sch]
2019-05-27 ultimos ajustes pcb
    [receptor_same.brd]
2019-05-27 archivos de fabricacion
    [gerber_job.gbrjob, receptor_same.GBL, receptor_same.GBO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]
2019-06-24 misc esquematico
    [receptor_same.sch]
2020-05-05 recepcion de mensajes same
2020-06-21 clase config hasta codigos de evento y area, pendiente save y reload con pruebas
2020-06-21 set defaults y fixes para busqueda en listas vacias
    [Config.cpp, TestConfig.ino]
2020-06-27 tabla de comandos y getCmd
2020-06-28 volumen de 0 a 10, fix setAudio y setRelay, clarificar periodo rmt y rwt
    [Config.cpp]
2020-07-04 pruebas codigo de area con comodin
2020-07-04 buscar codigo de area con comodin y periodos rwt y rmt en millis
2020-07-04 filtros de area y evento por mensaje, timer same, rwt y rmt
2020-07-05 leds begin, error, wait, wait rt y alert
    [IO.cpp, IO.h, TestIO.ino]
2020-07-05 ledRefresh -> ledsRefresh
2020-08-28 guardamos periodos de tiempos en millis, audio 2
2021-04-17 raspberry pi logger
2022-07-24 fix comparacion bandera rwt dos veces en lugar de rmt
    [ReceptorSame.ino]
2023-01-16 pruebas de integracion para mejoras
2023-01-16 procesamos dos cabeceras si recibimos un fin de mensaje
2023-01-17 configuracion same para defaults
2023-01-18 soporte para reproductor de audio externo
2023-01-29 avanzamos version de configuracion
2023-01-29 eliminamos configuracion de IO
2023-10-05 esquematico y software del prototipo del receptor de alertas
    [prototipo_receptor_same.sch]

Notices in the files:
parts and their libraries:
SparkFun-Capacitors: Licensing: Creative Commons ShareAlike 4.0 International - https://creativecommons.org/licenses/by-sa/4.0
